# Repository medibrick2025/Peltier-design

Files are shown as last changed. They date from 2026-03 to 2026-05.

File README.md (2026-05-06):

# Peltier Brick Controller

## Description

The Peltier Brick is a modular controller designed to operate two independent Peltier heating and cooling modules. Each channel uses an IR2113 gate driver together with IRF3205 MOSFETs to form a switching stage that allows bidirectional current flow. By reversing the current through the Peltier device, the system can provide both heating and cooling.

A microcontroller generates PWM signals to regulate the power delivered to each Peltier element and control the temperature of each channel independently.

---

## PCB Layout

The images below show the front and back sides of the PCB design.

<p align="center">
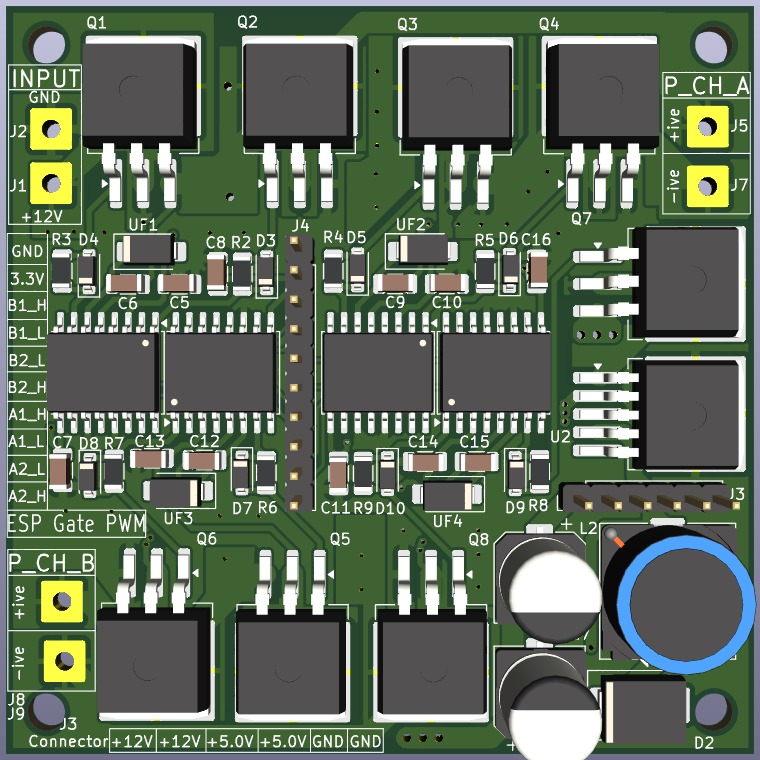
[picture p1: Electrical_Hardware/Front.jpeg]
PCB Front Side
  
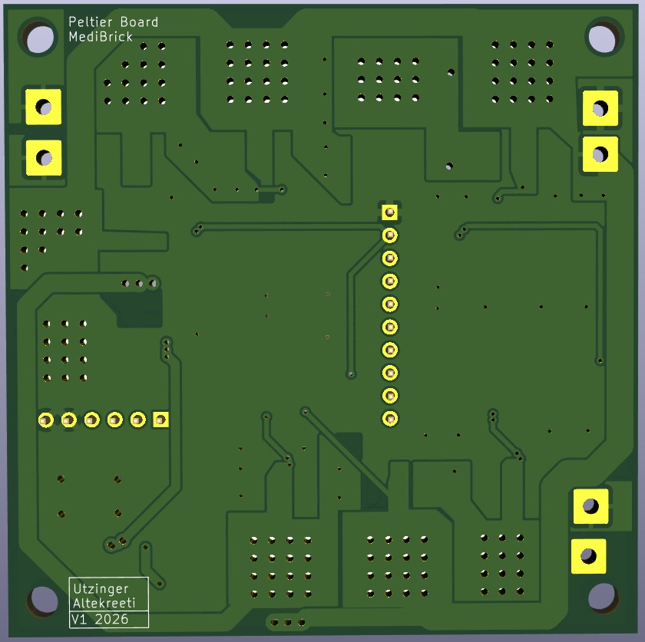
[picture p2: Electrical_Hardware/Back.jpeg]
PCB Back Side
  
</p>

## Schematics

The image below shows the circuit schematic for the PCB.

<p align="center">
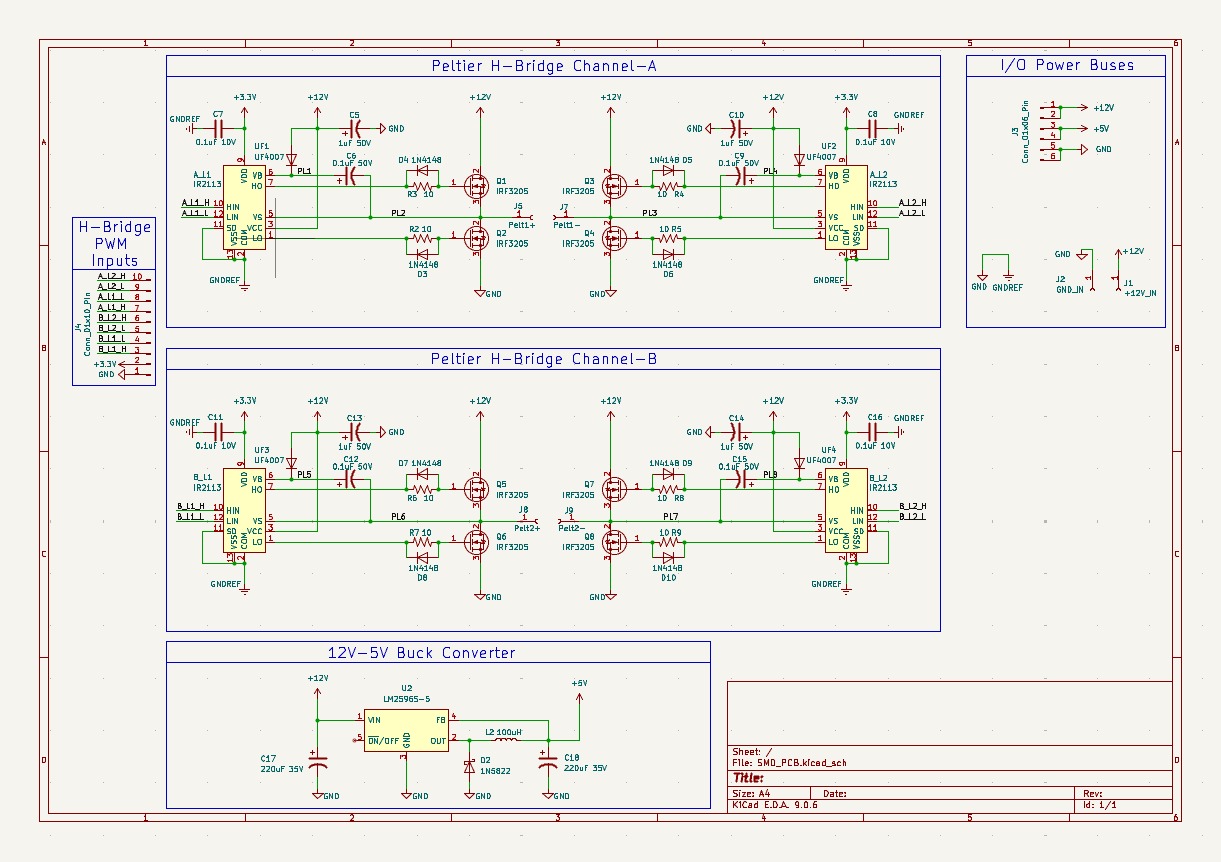
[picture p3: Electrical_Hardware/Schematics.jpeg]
PCB Schematics
  
</p>

---

## Electrical Hardware

KiCad PCB design files and manufacturing outputs:

[Electrical Hardware](Electrical_Hardware/)

---

## GUI

The project also includes a graphical user interface (GUI) for system control and monitoring.

The GUI supports basic interaction with the Peltier system, including control input and display of system status.

[GUI](GUI/)

---

## Datasheets and Design Notes

Power driver discussion and reference documentation:

[DataSheet](DataSheet/)

---

## Assembly and instructions

These are the [Assebly and Instructions](Assembly_and_instructions/)

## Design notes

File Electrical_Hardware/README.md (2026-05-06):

# PCB Ordering Guide

This folder contains the PCB manufacturing files for the Peltier hardware system.  

## PCB File Locations

```text
Electrical_Hardware/12V_PCB/SMD_PCB/
Electrical_Hardware/48V_PCB/SMD_PCB_HV/
Electrical_Hardware/Faceplate_PCB/
```

## How to Order the PCB

1. Download this repository from GitHub by clicking **Code → Download ZIP**, or clone it with Git.  

2. Open the `Electrical_Hardware` folder and choose the PCB folder you want to order.  

3. Compress the selected PCB folder into a `.zip` file.  

```text
12V_PCB/SMD_PCB/       →  SMD_PCB.zip
48V_PCB/SMD_PCB_HV/    →  SMD_PCB_HV.zip
Faceplate_PCB/         →  Faceplate_PCB.zip
```

4. Upload the `.zip` file to PCBWay as the Gerber file package.  

5. Check the PCB preview, confirm the order settings, and submit the order.  

PCBWay will review the files before manufacturing.

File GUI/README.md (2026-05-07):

## 1. Enable TTL Mode

Before using the display with the ESP32 or other microcontrollers:

Locate the TTL/232 jumper pads on the back of the display.
Enable **TTL mode** by soldering or shorting the bridge labeled:
- **ON = TTL**
- **OFF = 232**

### TTL OFF Default

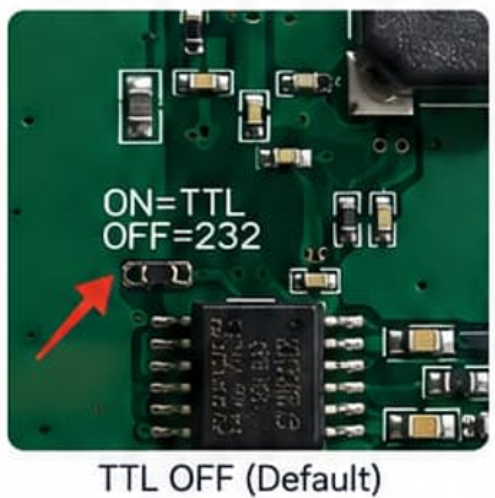
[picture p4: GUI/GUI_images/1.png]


**Figure:** TTL mode is OFF by default.

### TTL ON Shorted

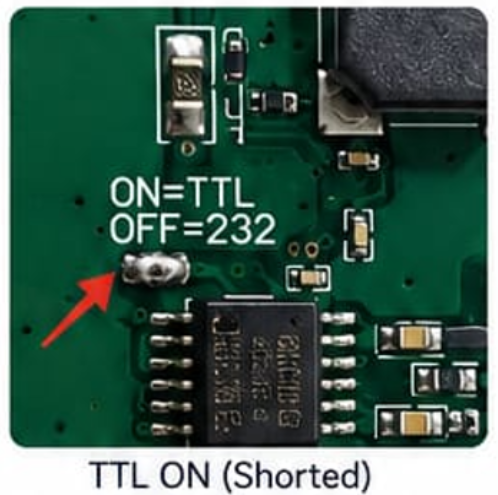
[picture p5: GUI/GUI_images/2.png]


**Figure:** Short the bridge to enable TTL mode.

> **Important:** If TTL mode is not enabled, the display may not communicate correctly with the controller.

---

## 2. Prepare the SD Card



Download the Dwin_Set folder provided with your GUI files.
Use a high-quality SD card (16GB or larger recommended).
Format the SD card to FAT32 if needed.
Copy the entire Dwin_Set folder to the root directory of the SD card.
- High-quality SD card preferred

---

## 3. Flash the GUI to the Display

### Step 1: Power the Display

Power the display using:

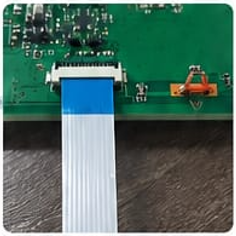
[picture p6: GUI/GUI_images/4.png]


The ribbon cable power connection, or
5V and GND wires.

### Step 2: Insert the SD Card WHILE the Display is ON

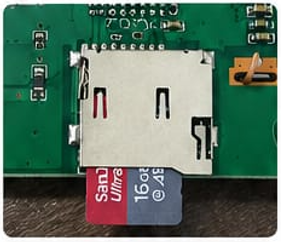
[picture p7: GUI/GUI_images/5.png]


Insert the SD card into the display while the display remains powered ON..

### Step 3: Wait for the Update Screen

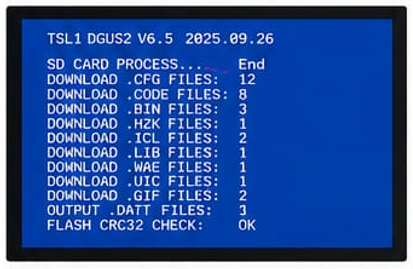
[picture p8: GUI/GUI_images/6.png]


( Keep the SD card inside and turn off the display while the Sd card in inside then turn it back on ) A blue update screen will appear. The display will begin downloading and flashing the GUI files.

Wait until the screen shows **End** on the top right.

Do not remove power or remove the SD card during this process.

---

## 4. Restart the Display and Remove the SD Card

### Step 1: Disconnect Power

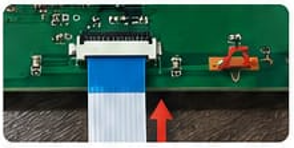
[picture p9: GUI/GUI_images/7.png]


After the update is complete, disconnect the power from the display.

### Step 2: Remove the SD Card

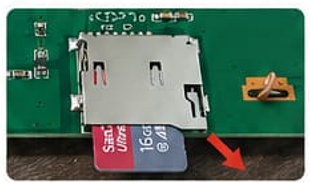
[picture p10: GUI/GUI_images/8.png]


Remove the SD card from the display.

### Step 3: Power the Display Again



Turn the power back on after removing the SD card.

---

## 5. GUI Ready

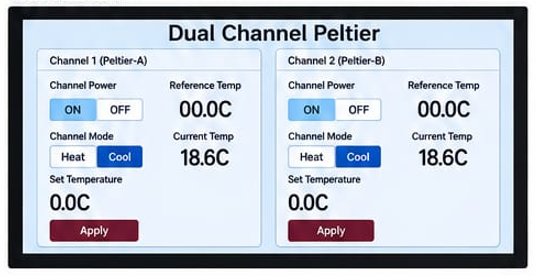
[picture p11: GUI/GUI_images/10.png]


After restarting the display, the Dual Channel Peltier GUI should appear.

The display is now ready to use with the Peltier controller.

---

## Basic Setup Summary

1. Enable TTL mode by shorting the TTL bridge.
2. Copy the complete `Dwin_Set` folder to an SD card.
3. Power the display with 5 V.
4. Insert the SD card into the display.
5. turn off the display while SD card is inside then turn it back on 
6. wait untill the blue update screen shows End 
7. disconnect from power and remove SD card 
8. turn the display on and the GUI is ready to Use.
9. Confirm that the GUI appears on the screen.

---

## Notes

- Use a high-quality SD card, preferably 16 GB or larger.
- Format the SD card as FAT32 if the update fails.
- Do not remove power while the display is updating.
- Do not remove the SD card during the update process.
- Always enable TTL mode before connecting the display to the ESP32 controller.
- If the GUI does not appear after restart, repeat the update process with a freshly formatted SD card.

---

## Important Warning

**Always enable TTL mode before flashing or using the display.**

If TTL mode is not enabled, the display may not communicate correctly with the ESP32 controller.

---
<p align="center">
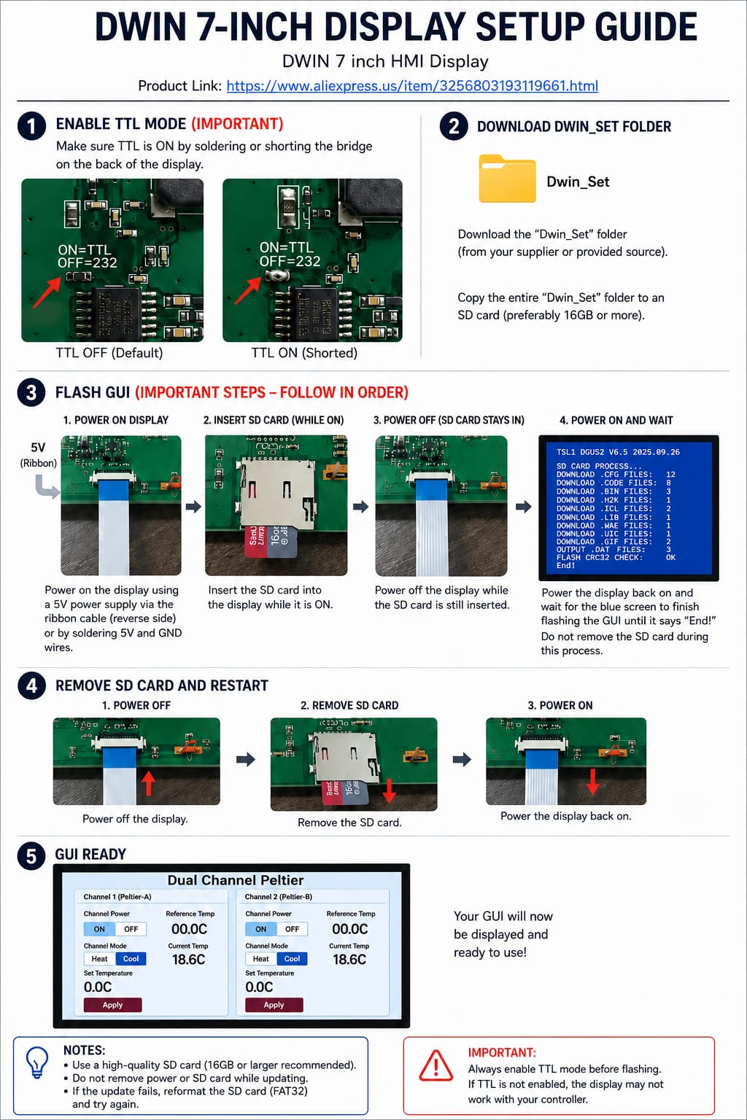
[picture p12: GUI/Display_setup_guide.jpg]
DWIN display setup guide
  
</p>

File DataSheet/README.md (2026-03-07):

## Here is the DataSheet and Power Solutions

[DataSheet](IR2113SPBF.pdf)

[Power Solutions](power_solutions.md)

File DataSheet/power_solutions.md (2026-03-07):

# Power Control Solutions

## Breakout Boards
| Source | Link | Voltage | Amperage | Logic| Cost |
| --- |--- |--- |--- |--- | --- |
| Amazon L298N |[Link](https://a.co/d/1e84QhE)|  5-35V | 2A | 5V | $3.50
| Amazon BTS7960 | [Link](https://a.co/d/3osQzfE) | 6V-27V | 43A | 3.3-5V|  $7
| Amazon DRV8871 | [Link](https://a.co/d/hwcKjuL) | 6.5-45V| 3.6A | 1.8-5V |  $4.50
| Pololu Simple Motor Driver| [Link](https://www.pololu.com/product/1365)| 6.5-50V| 12A| USB |$135
| Pololu 8874 | [Link](https://www.pololu.com/product/4035) | 37V | 2.1A | 1.8-5V | $12
| Pololu 8876 | [Link](https://www.pololu.com/product/4036) | 37V | 1.3A | 1.8-5V | $9
| Sparkfun L298| [Link](https://www.sparkfun.com/sparkfun-ardumoto-motor-driver-shield.html) | 46V | 2A |3.3-5V| $25
| Sparkfun TB6612| [Link](https://www.sparkfun.com/tb6612-1-2a-dc-stepper-motor-driver-breakout-board.html)|  15V | 1.2A | 5V | retired
| Adafruit DRV8833| [Link](https://www.adafruit.com/product/3297) | 10V | 2A | | $6
| Adafruit DRV8871| [Link](https://www.adafruit.com/product/3190)| 6.5-45V | 3.6A| 1.8-5V | $7.50

## Discrete Builds

### Gate driver IR2113 and FET IRF3205
IRF3205 is *outdate design*

- requires 12V gate driver
- IRF3205 55V, 110A, 8mOhm, $1.45
- requires careful timing
- external current Senses
- allows for high switching rates

Optimizations with replacement parts

Replace FET with:

| Device | Voltage | Current | RDS ON | Price
| --- | --- | --- | --- | --- |
| IRLB3034 | 40V | 195-300A | 1.7mOhm | $2-4, end of life
| IRLB8743 | 30V | 150A | 3.2mOhm | $ 0.7-1.5 
| BSC010NE2LS | 25V |  100A | 1.1mOhm | $3-5
| AOI4184 | 40V | 40-50A| 7-8 mOhm | $0.7
| AOI518 | 30V | 54A | 8mOhm | obsolete
| BSC340N08 | 80V | 23A | 34mOhm | $1.30
| IPB017N10N5 | 100V |  120-180A| 1.5mOhm | $5-7
| IPB017N06N5 | 60V |  100-180A|  1.7mOhm | $6.25
| IPP034N06L3 | 30V | 80A | 3.4mOhm | $1-2 restricted availability
| STN3NF06L | 60V | 4A | 100mOhm | $1.59
| FQP30N06L | 60V | 32A | 35mOhm | $1.8
| onsemi RFP50N06| 60V | 50A | 22mOhm | $0.83
| NTE2996 | 60V | 84A  | 12mOhm | $2.85
| **TI CSD18532Q5B**| 60V | 100A | 3.2mOhm | $2.99 US $1.58 CHN
| **TI CSD18540Q5B**| 60V | 100A | 2.2mOhm | $3.05 US $1.51 CHN

Gate Drivers:

- UCC27211A 12V gate, simple no current sense, half bridge, $2.60
- IRS2186 10-20V gate, simple not current sense, half bridge $1.95
- MP6528 12V gate, full bridge, protection circuits, for 5-60V FET $2.51 (no stock JLPCP, in stock US)

- **Smart Gate Driver**, full bridge [DRV8701](https://www.ti.com/product/DRV8701) for 47V FET. $2.85 US, $0.59 CHN

- **Smart Gate Driver**, 2 x full bridge [DRV8704](https://www.ti.com/product/DRV8704) for 47 FET.  $4.87 US, $5.54 CHN

Also check out example design from Texas Instruments for [single H bridge](https://www.ti.com/tool/DRV8701EVM) and for [Dual H bridge](https://www.ti.com/tool/DRV8704EVM) with eval kit for $60.

### "Smart" H Bridge: Infinion BTS7960 / BTN7970 / BTN8982
*breakout board available*

builtin protection, simpler

half bridge:
- BTS7960 45V, 43A, 25kHz, 16mOhm, 5V logic, current sense, no stock china, USA
- BTN7960 45V, 44A, 25kHz, 30mOhm, 5V logic, current sense, no stock
- BTN7970 45V, 44A, 25kHz, 30mOhm, 5V logic, current sense, $5 obsolete
- **BTN8982** 40V, 44A, 25kHz, 20mOhm, 5V logic, current sense (newer) $3.82 CHN $5.6 US

Requires 3V to 5V logic buffer with TI SN74HCS244 to operate with 3.3V micro controllers

Also check out example design from infinion on [hackster](https://www.hackster.io/infineon/products/dc-motor-control-shield-with-btn8982ta?ref=project-0f6579)

P = I x R x I = 160*0.02 = 3.2 W heat @ 40A

### Integrated H Bridge DRV8874 / DRV8876 / DRV887x
*breakout board available*

Easy to use
builtin current limit or current sense
simple interface

- DRV8871 6.5 - 45V, 3.6A, protection, current limiter
- DRV8876 4.5 - 37V, 3.5A, 700mOhm, 1.8-5V logic, current sense output
- DRV8874 4.5 - 37V, 6A, 200mOhm, 1.8-5V logic, current sense output, $3 

P = I x R x I 36*0.2 = 7.2 W heat @ 6A

This is lower cost and fully integrated solution but thermal management at 6A will require careful design as it has high RDSON

### Half H Bridge DRV81XX
- DRV8145 4.5 - 35V, 46A, 16mOhm, 125kHz, $6.87, half bridge only
- DRV8144 4.5 - 35V, 30A, 24mOhm $5.50, half bridge only

## Temperature
ADS1220
 
> Adapted from the MediBrick project:  
> https://github.com/MediBrick/MediBrick/blob/main/power_solutions.md

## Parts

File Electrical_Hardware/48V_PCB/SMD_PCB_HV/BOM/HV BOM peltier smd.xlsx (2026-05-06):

Item # | Designator | Qty | Manufacturer | Mfg Part # | LCSC Part# | Description / Value | Packaging | Type | Cost | Footprint | Remark
1 | Q1,Q2,Q3,Q4,Q5,Q6,Q7,Q8 | 8 | HXY MOSFET (https://www.lcsc.com/brand-detail/13437.html) | IRFS4310ZTRLPBF-HXY | C20606279 (https://www.lcsc.com/product-detail/C20606279.html?s_z=n_IRFS4310Z) | N-Channel 100V 260A 379W Surface Mount TO-263 | TO-263 | SMD |  | TO-263-3_TabPin2
2 | R9,R6,R4,R2,R5,R3,R8,R7 | 8 | YAGEO (https://www.lcsc.com/brand-detail/396.html) | RC1206FR-0710RL | C108080 (https://www.lcsc.com/product-detail/C108080.html?s_z=n_RC1206FR-0710) | RES 10Ω ±1% 250mW 1206 | 1206 | SMD |  | R_1206_3216Metric
3 | B_L2,A_L2,A_L1,B_L1 | 4 | Minos (https://www.lcsc.com/brand-detail/13052.html) | IR2113S-MNS | C47967297 (https://www.lcsc.com/product-detail/C47967297.html?s_z=n_%2509%2520IR2113) | IR2113 | SOIC-16 | SMD |  | SOIC-16W_7.5x10.3mm_P1.27mm
4 | C16,C8,C11,C7 | 4 | Samsung Electro-Mechanics (https://www.lcsc.com/brand-detail/254.html) | CL31B104KBCNNNC | C24497 (https://www.lcsc.com/product-detail/C24497.html?s_z=n_0.1uF%252010V%25201206) | 0.1uF 50V | 1206 | SMD |  | C_1206_3216Metric
5 | D5,D6,D10,D4,D8,D9,D3,D7 | 8 | JSMSEMI (https://www.lcsc.com/brand-detail/12313.html) | 1N4148W | C917030 (https://www.lcsc.com/product-detail/C917030.html?s_z=n_1N4148%2520sod-123) | 1N4148 | D_SOD-123 | SMD |  | D_SOD-123
6 | C14,C13,C10,C9,C12,C5,C6,C15 | 8 | YAGEO (https://www.lcsc.com/brand-detail/396.html) | AC1206KKX7R0BB105 | C2936627 (https://www.lcsc.com/product-detail/C2936627.html) | 1uF ±10% 100V Ceramic Capacitor X7R 1206 | 1206 | SMD |  | C_1206_3216Metric
7 | R1 | 1 | YAGEO (https://www.lcsc.com/brand-detail/396.html) | RT0805FRE07215KL | C706379 (https://www.lcsc.com/product-detail/C706379.html?s_z=n_RES%2520215k%25CE%25A9_0805) | RES 215kΩ ±1% 125mW 0805 | R_0805_2012Metric | SMD |  | R_0805_2012Metric
8 | R10 | 1 | YAGEO (https://www.lcsc.com/brand-detail/396.html) | RT0805BRD0744K2L | C865498 (https://www.lcsc.com/product-detail/C865498.html) | RES 44.2kΩ ±0.1% 125mW 0805 | 805 | SMD |  | R_0805_2012Metric
9 | R14,R15 | 2 | YAGEO (https://www.lcsc.com/brand-detail/396.html) | RC0805FR-07100KL | C96346 (https://www.lcsc.com/product-detail/C96346.html) | RES 100kΩ ±1% 125mW 0805 | 805 | SMD |  | R_0805_2012Metric
10 | R11 | 1 | YAGEO | RC0805FR-07147KL | C483012 (https://www.lcsc.com/product-detail/C483012.html?s_z=n_RC0805FR-07147KL) | RES 147kΩ ±1% 125mW 0805 | 805 | SMD |  | R_0805_2012Metric
11 | R16 | 1 | FOJAN | FRC0805F2323TS | C2974036 (https://www.lcsc.com/product-detail/C2974036.html) | RES 232kΩ ±1% 125mW 0805 | 805 | SMD |  | R_0805_2012Metric
12 | R17 | 1 | YAGEO | RC0805FR-0730KL | C126352 (https://www.lcsc.com/product-detail/C126352.html?s_z=n_RC0805FR-0730KL) | RES 30kΩ ±1% 125mW 0805 | 805 | SMD |  | R_0805_2012Metric
13 | R12 | 1 | UNI-ROYAL (https://www.lcsc.com/brand-detail/99.html) | 0805W8F1052T5E | C40086 (https://www.lcsc.com/product-detail/C40086.html) | RES 10.5kΩ ±1% 125mW 0805 | 805 | SMD |  | R_0805_2012Metric
14 | R13 | 1 | YAGEO (https://www.lcsc.com/brand-detail/396.html) | RC0805FR-071ML | C107700 (https://www.lcsc.com/product-detail/C107700.html?s_z=n_RC0805FR-010R5KL) | RES 1MΩ ±1% 125mW 0805 | 805 | SMD |  | R_0805_2012Metric
15 | U1 | 1 | TI (https://www.lcsc.com/brand-detail/100.html) | TPS54360DDAR | C44377 (https://www.lcsc.com/product-detail/C44377.html?s_z=n_TPS54360DDA) | 60V Input, 3.5A Output Step-Down DC-DC Converter | SOIC-8-EP | SMD |  | TI_SO-PowerPAD-8_ThermalVias
16 | U4 | 1 | TI (https://www.lcsc.com/brand-detail/100.html) | TPS562203DRLR | C22445511 (https://www.lcsc.com/product-detail/C22445511.html?s_z=n_TPS562203) | 4.2V to 17V Input, 2A Output, Synchronous Buck Converter | SOT-563 | SMD |  | SOT-563
17 | C1 | 1 | Samsung Electro-Mechanics (https://www.lcsc.com/brand-detail/254.html) | CL32B225KCJSNNE | C55151 (https://www.lcsc.com/product-detail/C55151.html?s_z=n_2.2uF%2520100V%25201210) | 2.2uF ±10% 100V Ceramic Capacitor X7R 1210 | 1210 | SMD |  | C_1210_3225Metric
18 | C2 | 1 | YAGEO (https://www.lcsc.com/brand-detail/396.html) | AS0805KRX7R0BB472 | C1853298 (https://www.lcsc.com/product-detail/C1853298.html?s_z=n_4.7nF%2520100V%25200805) | 4.7nF X7R ±10% 100V 0805 Ceramic Capacitors RoHS | 805 | SMD |  | C_0805_2012Metric
19 | C3 | 1 | MEGSINE | MCA08HQ8R2C251T7 | C42432098 (https://www.lcsc.com/product-detail/C42432098.html?s_z=n_CAP%2520CER%25208.2pF%2520100V%25200805) | CAP CER 8.2pF 250V 0805 | 805 | SMD |  | C_0805_2012Metric
20 | C24 | 1 | YAGEO (https://www.lcsc.com/brand-detail/396.html) | CC0805MKX5R6BB226 | C109314 (https://www.lcsc.com/product-detail/C109314.html) | CAP CER 22uF 10V X5R 0805 | 805 | SMD |  | C_0805_2012Metric
21 | C23 | 1 | muRata (https://www.lcsc.com/brand-detail/79.html) | GRM0335C1E180FA01D | C488333 (https://www.lcsc.com/product-detail/C488333.html?s_z=n_%2509%2520C488333) | CAP CER 18pF 25V C0G 0201 | 201 | SMD |  | C_0201_0603Metric
22 | C4,C21,C22,C25 | 1 | YAGEO (https://www.lcsc.com/brand-detail/396.html) | CC0603KRX7R9BB104 | C14663 (https://www.lcsc.com/product-detail/C14663.html?s_z=n_100nF%252050V%25200603) | CAP CER 100nF 50V X7R 0603 | 603 | SMD |  | C_0603_1608Metric
24 | C20 | 1 | CCTC (https://www.lcsc.com/brand-detail/11714.html) | TCC0805X5R106K250FT | C5448891 (https://www.lcsc.com/product-detail/C5448891.html?s_z=n_10uF%252025V%25200805) | CAP CER 10uF 25V X5R 0805 | 805 | SMD |  | C_0805_2012Metric
25 | C19 | 1 | Chinocera (https://www.lcsc.com/brand-detail/12099.html) | HGC1206R5476M250NSPJ | C22367835 (https://www.lcsc.com/product-detail/C22367835.html?s_z=n_47uF%252025V%25201206) | CAP CER 47uF 25V X5R 1206 | 1206 | SMD |  | C_1206_3216Metric
26 | D13,D12,D2,D11 | 4 | VISHAY (https://www.lcsc.com/brand-detail/91.html) | US1M-E3/61T | C81191 (https://www.lcsc.com/product-detail/C81191.html?s_z=n_US1M) | Diode 1kV 1A SMA(DO-214AC) | SMA(DO-214AC) | SMD |  | D_SMA
27 | D15 | 1 | MDD(Microdiode Semiconductor) (https://www.lcsc.com/brand-detail/164.html) | SS510B | C65011 (https://www.lcsc.com/product-detail/C65011.html?s_z=n_SS510B) | DIODE SCHOTTKY 100V SMB(DO-214AA) | SMB(DO-214AA) | SMD |  | D_SMB
28 | L3 | 1 | cjiang (https://www.lcsc.com/brand-detail/11425.html) | FTC404030S6R8MBCA | C39676084 (https://www.lcsc.com/product-detail/C39676084.html) | FIXED IND 6.8uH 4.2A 62mΩ SMD,4.1x4.1mm | SMD,4.1x4.1mm | SMD |  | L_Changjiang_FTC404030S
29 | L1 | 1 | BOURNS (https://www.lcsc.com/brand-detail/377.html) | SRR1260-220M | C3224283 (https://www.lcsc.com/product-detail/C3224283.html?s_z=n_L_Bourns_SRR1260) | 4A 22uH 43mΩ 3.7A ±20% SMD,12.5x12.5mm Fixed Inductors RoHS | SMD,12.5x12.5mm | SMD |  | L_Bourns_SRR1260
30 | J4 | 1 | JST (https://www.lcsc.com/brand-detail/853.html) | B10B-PHDSS-B(LF)(SN) | C158039 (https://www.lcsc.com/product-detail/C158039.html) |  |  |  |  | JST_PHD_B10B-PHDSS_2x05_P2.00mm_Vertical
31 | J1,J2,J6 | 3 | Changzhou Amass Elec (https://www.lcsc.com/brand-detail/1029.html) | XT30PW-M30.G.Y | C431092 (https://www.lcsc.com/product-detail/C431092.html?s_z=n_AMASS_XT30PW-F_1x02_P2.50mm_Horizontal) | Banana and Tip Connector Adapters RoHS | - |  |  | AMASS_XT30PW-F_1x02_P2.50mm_Horizontal
32 | J5 | 1 |  |  |  |  |  |  |  | PinHeader_1x11_P2.54mm_Vertical | DNP

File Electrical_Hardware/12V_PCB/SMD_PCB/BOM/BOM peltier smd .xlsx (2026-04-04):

Item # | Designator | Qty | Manufacturer | Mfg Part # | LCSC Part# | U.S. Distributor | Description / Value | Packaging | Type | Cost | Footprint | Remark
1 | Q4,Q1,Q8,Q7,Q2,Q5,Q6,Q3 | 8 | JSMSEMI (https://www.lcsc.com/brand-detail/12313.html) | IRF3205S-JSM | C2874633 (https://www.lcsc.com/product-detail/C2874633.html?s_z=n_IRF3205) |  | IRF3205 55V 110A 200W Surface Mount TO-263 | TO-263 | SMD |  | TO-263-3_TabPin2
2 | R9,R6,R4,R2,R5,R3,R8,R7 | 8 | YAGEO (https://www.lcsc.com/brand-detail/396.html) | RC1206FR-0710RL | C108080 (https://www.lcsc.com/product-detail/C108080.html?s_z=n_RC1206FR-0710) |  | RES 10Ω ±1% 250mW 1206 | 1206 | SMD |  | R_1206_3216Metric
3 | D2 | 1 | onsemi (https://www.lcsc.com/brand-detail/94.html) | SS34 | C154551 (https://www.lcsc.com/product-detail/C154551.html?s_z=n_SS34) |  | Diode 40V 3A SMC(DO-214AB) | SMC(DO-214AB) | SMD |  | D_SMC
4 | UF3,UF4,UF1,UF2 | 4 | VISHAY (https://www.lcsc.com/brand-detail/91.html) | US1M-E3/61T | C81191 (https://www.lcsc.com/product-detail/C81191.html?s_z=n_US1M) |  | Diode 1kV 1A SMA(DO-214AC) | SMA(DO-214AC) | SMD |  | D_SMA
5 | C14,C13,C10,C5 | 4 | Samsung Electro-Mechanics (https://www.lcsc.com/brand-detail/254.html) | CL31B105KBHNNNE | C1848 (https://www.lcsc.com/product-detail/C1848.html?s_z=n_1uF%252050V%25201206) |  | CAP CER 1uF 50V X7R 1206 | 1206 | SMD |  | C_1206_3216Metric
6 | B_L1,B_L2,A_L2,A_L1 | 4 | Minos (https://www.lcsc.com/brand-detail/13052.html) | IR2113S-MNS | C47967297 (https://www.lcsc.com/product-detail/C47967297.html?s_z=n_%2509%2520IR2113) |  | IR2113 | SOIC-16 | SMD |  | SOIC-16W_7.5x10.3mm_P1.27mm
7 | C18,C17 | 2 | JIERR (https://www.lcsc.com/brand-detail/18279.html) | CS35V220M8X10 | C48935393 (https://www.lcsc.com/product-detail/C48935393.html?s_z=n_220uF%252035V%2520CP_Elec_8x10) |  | CAP ALUM 220uF ±20% 35V SMD | 8x10 | SMD |  | CP_Elec_8x10
8 | C16,C8,C11,C7 | 4 | Samsung Electro-Mechanics (https://www.lcsc.com/brand-detail/254.html) | CL31B104KBCNNNC | C24497 (https://www.lcsc.com/product-detail/C24497.html?s_z=n_0.1uF%252010V%25201206) |  | 0.1uF 50V | 1206 | SMD |  | C_1206_3216Metric
9 | D5,D6,D10,D4,D8,D9,D3,D7 | 8 | JSMSEMI (https://www.lcsc.com/brand-detail/12313.html) | 1N4148W | C917030 (https://www.lcsc.com/product-detail/C917030.html?s_z=n_1N4148%2520sod-123) |  | 1N4148 | D_SOD-123 | SMD |  | D_SOD-123
10 | C9,C12,C6,C15 | 4 | Samsung Electro-Mechanics (https://www.lcsc.com/brand-detail/254.html) | CL31B104KBCNNNC | C24497 (https://www.lcsc.com/product-detail/C24497.html?s_z=n_0.1uF%252010V%25201206) |  | 0.1uF 50V | 1206 | SMD |  | C_1206_3216Metric
11 | L2 | 1 | COILMX (https://www.lcsc.com/brand-detail/11934.html) | MBH125-101M | C2981396 (https://www.lcsc.com/product-detail/C2981396.html?s_z=n_C2981396) |  | 100uH 2A 178mΩ Unshielded Inductor ±20% SMD,12.5x12.5mm Fixed Inductors RoHS | SMD,12.5x12.5mm | SMD |  | SMD,12.5x12.5mm
12 | U2 | 1 | TI | LM2596S-5.0/NOPB | C116713 (https://www.lcsc.com/product-detail/C116713.html?s_z=n_LM2596S-5.0) |  | LM2596 150-kHz 3-A Step-Down Voltage Regulator | TO-263-5 | SMD |  | TO-263-5_TabPin3
13 | J1 | 1 |  |  |  |  | +12V_IN |  | SMD |  | SolderWire-1sqmm_1x01_D1.4mm_OD3.9mm | DNP
14 | J2 | 1 |  |  |  |  | GND_IN |  | SMD |  | SolderWire-1sqmm_1x01_D1.4mm_OD3.9mm | DNP
15 | J3 | 1 |  |  |  |  | Conn_01x06_Pin |  | SMD |  | PinHeader_1x06_P2.54mm_Vertical | DNP
16 | J4 | 1 |  |  |  |  | Conn_01x10_Pin |  | SMD |  | PinHeader_1x10_P2.54mm_Vertical | DNP
17 | J5 | 1 |  |  |  |  | Pelt1+ |  | SMD |  | SolderWire-1sqmm_1x01_D1.4mm_OD3.9mm | DNP
18 | J7 | 1 |  |  |  |  | Pelt1- |  | SMD |  | SolderWire-1sqmm_1x01_D1.4mm_OD3.9mm | DNP
19 | J8 | 1 |  |  |  |  | Pelt2+ |  | SMD |  | SolderWire-1sqmm_1x01_D1.4mm_OD3.9mm | DNP
20 | J9 | 1 |  |  |  |  | Pelt2- |  | SMD |  | SolderWire-1sqmm_1x01_D1.4mm_OD3.9mm | DNP

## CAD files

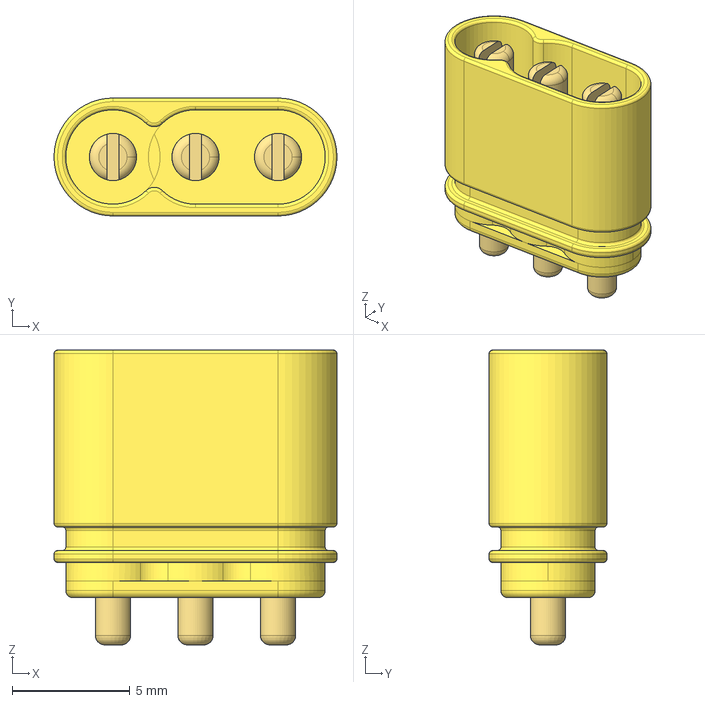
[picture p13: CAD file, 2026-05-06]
Electrical_Hardware/Faceplate_PCB/Side_Plate_PeltierBrick/Side_Plate_PeltierBrick/3dshapes/Amass_MR30PB-M.step
12.0 x 5.00 x 12.5 mm

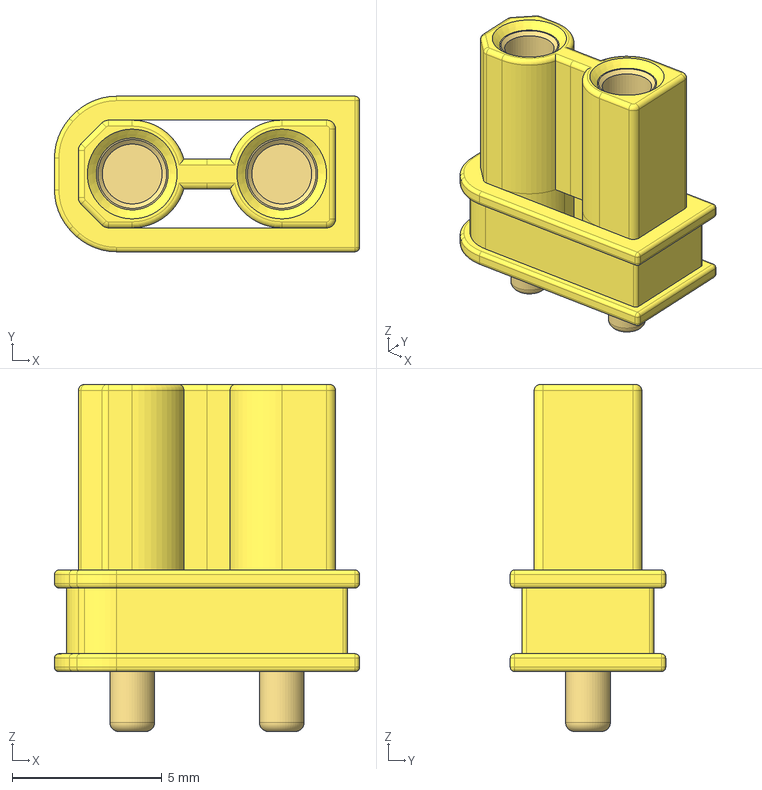
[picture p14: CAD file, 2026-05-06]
Electrical_Hardware/Faceplate_PCB/Side_Plate_PeltierBrick/Side_Plate_PeltierBrick/3dshapes/Amass_XT30UPB-F.step
10.2 x 5.20 x 11.6 mm

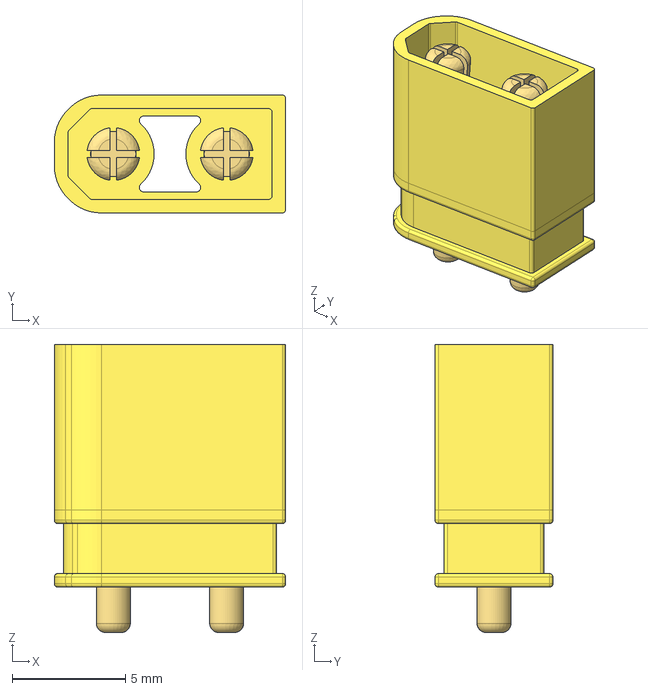
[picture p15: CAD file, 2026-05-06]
Electrical_Hardware/Faceplate_PCB/Side_Plate_PeltierBrick/Side_Plate_PeltierBrick/3dshapes/Amass_XT30UPB-M.step
10.2 x 5.20 x 12.7 mm

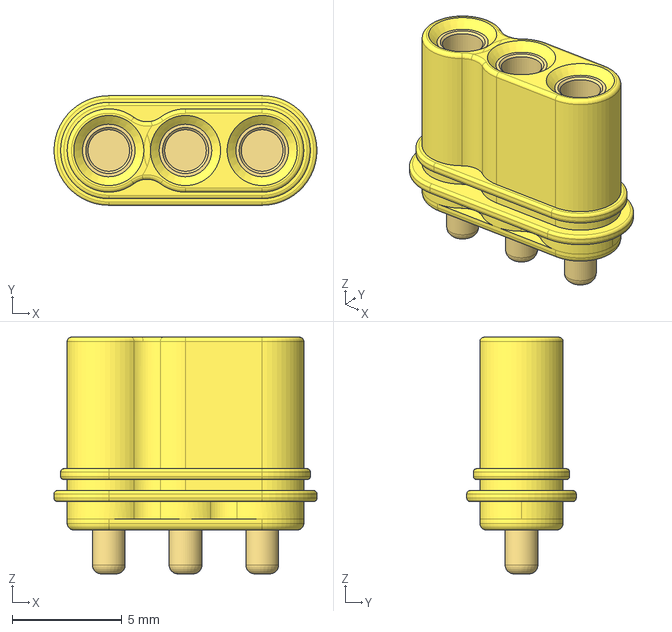
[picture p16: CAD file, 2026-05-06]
Electrical_Hardware/Faceplate_PCB/Side_Plate_PeltierBrick/Side_Plate_PeltierBrick/3dshapes/Amass_MR30PB-FB.step
12.0 x 5.00 x 10.8 mm

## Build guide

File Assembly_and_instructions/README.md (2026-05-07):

## 1. Components

| Component | Image | Description |
|---|---|---|
| TMP36GZ Temperature Sensor |  | Analog temperature sensor |
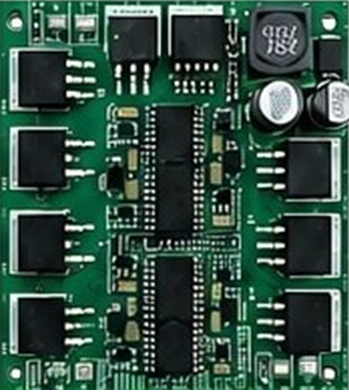
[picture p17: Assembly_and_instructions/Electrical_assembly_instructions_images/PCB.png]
| Motor Driver PCB |  | Main motor driver and power board |
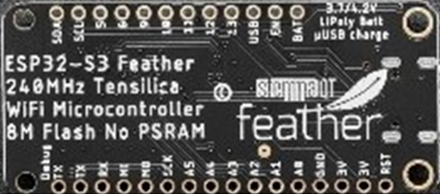
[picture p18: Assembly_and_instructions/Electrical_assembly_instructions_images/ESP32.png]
| ESP32-S3 Feather |  | Microcontroller board |
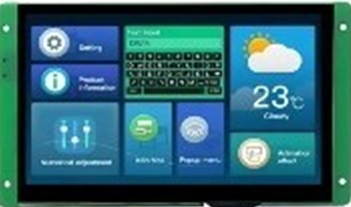
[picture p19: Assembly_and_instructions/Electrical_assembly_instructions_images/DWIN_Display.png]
| DWIN Display 7 inch |  | 7 inch DWIN HMI Display |
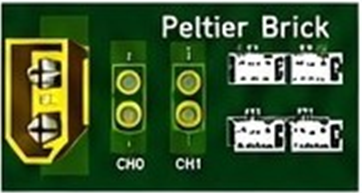
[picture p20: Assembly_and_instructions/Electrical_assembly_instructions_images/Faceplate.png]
| Face Plate |  | Panel with connectors and labels |

---

## 2. PCB to ESP32-S3 Connections

| PCB Signal | ESP32-S3 Pin | Description |
|---|---|---|
| 3.3V | 3V3 | ESP 3.3V power |
| GND | GND | Ground |
| B1-H | 5 | High Side B1 |
| B1-L | 6 | Low Side B1 |
| B2-L | 9 | Low Side B2 |
| B2-H | 10 | High Side B2 |
| A1-H | 11 | High Side A1 |
| A1-L | 12 | Low Side A1 |
| A2-L | 13 | Low Side A2 |
| A2-H | 8 / A5 | High Side A2 / Analog |
| 5V | USB | 5V power from USB |

**Tip:** Use short, twisted wires for motor outputs to reduce EMI.

---

## 3. TMP36 Temperature Sensor to ESP32-S3 Connections

| TMP36 Pin | ESP32-S3 Pin | Description |
|---|---|---|
| Pin 1 | VCC / 3V3 | DC voltage input, +2.7 V to 5.5 V |
| Pin 2 | A0 / Analog | Analog voltage output |
| Pin 3 | GND | Ground |

### Important TMP36 Wiring Note

Before connecting the TMP36 sensor to the ESP32:

1. Use a laboratory power supply set between 3 V and 5 V.
2. Set the current limit as low as possible.
3. Temporarily connect the TMP36 to the power supply.
4. Use a multimeter to verify the VCC and GND legs.
5. Confirm correct polarity before connecting the sensor to the ESP32.

**Warning:** Incorrect VCC/GND wiring may damage the sensor or microcontroller.



**Figure:** TMP36GZ temperature sensor reference.

---

## 4. DWIN Display to ESP32 and PCB Connections

| DWIN 7 inch | PCB Signal | ESP32-S3 Pin | Description |
|---|---|---|---|
| 5V | 5V | N.C. | Display power 5V |
| GND | GND | GND | Ground |
| RX2 | N.C. | TX2 | DWIN RX connects to ESP TX2 |
| TX2 | N.C. | RX2 | DWIN TX connects to ESP RX2 |

**Note:** `N.C.` means Not Connected.

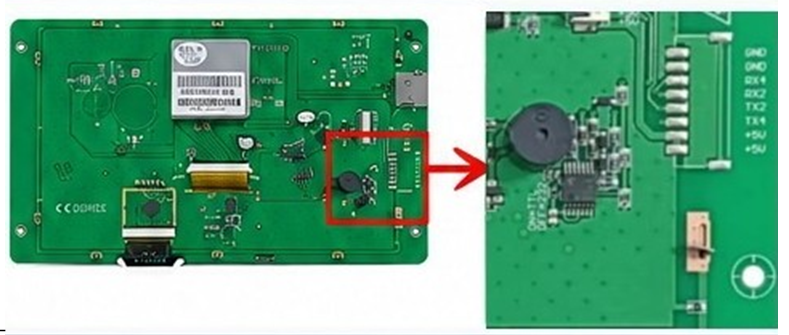
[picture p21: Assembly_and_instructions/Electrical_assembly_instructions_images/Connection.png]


**Figure:** DWIN display connection area and connector pin reference.

---

## 5. PCB to Face Plate Connections

| Face Plate Connection | PCB Connection | Description |
|---|---|---|
| XT60 Input | Power Supply Input | +12 V power input |
| CH0 XT30 | P_CH_A | Peltier Channel 0 |
| CH1 XT30 | P_CH_B | Peltier Channel 1 |

### Connector Notes

- XT60 provides the power supply input, **+12 V**.
- CH0 and CH1 use XT30 connectors for the Peltier brick channels.
- Ensure correct polarity before connecting the Peltier brick.
- RT1, RT2, RT3, and RT4 are for temperature sensor connections.

| Connector | Image | Description |
|---|---|---|
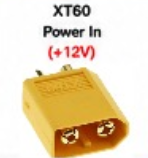
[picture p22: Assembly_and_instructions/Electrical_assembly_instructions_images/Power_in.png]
| XT60 Power Input |  | +12 V power input |
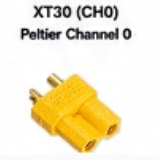
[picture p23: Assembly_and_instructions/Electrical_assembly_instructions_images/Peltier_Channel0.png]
| XT30 Channel 0 |  | Peltier Channel 0 |
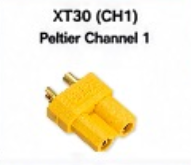
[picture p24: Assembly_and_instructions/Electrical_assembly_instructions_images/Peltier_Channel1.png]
| XT30 Channel 1 |  | Peltier Channel 1 |

---

## 6. Additional Recommendations

- Add a main inline fuse, 10–15 A, on the +12 V input.
- Add TVS diode protection on the +12 V input for surge protection.
- Add a bulk capacitor, 470–1000 µF, near the power input.
- Keep high-current motor and Peltier wiring away from signal wires.
- Use cable ties and strain relief to secure all wiring.
- Ensure proper ventilation for heat dissipation.

---

## 7. Final Assembly Notes

Before powering the system:

- Verify all wiring before powering the system.
- Ensure all grounds are shared properly.
- Double-check XT30 and XT60 polarity before applying power.
- Verify TMP36 orientation before connecting power.
- Use insulated wiring and avoid short circuits during assembly.
- Refer to the wiring AWG and ampacity guide to select wires for input power.
- A minimum of 16 AWG wire is recommended for the main power input.

### AWG Current Capacity Guide

| AWG | Maximum Current |
|---|---|
| 14 AWG | 30 A |
| 16 AWG | 20 A |
| 18 AWG | 15 A |
| 20 AWG | 10 A |

---

## 8. Important Warning

**Do not power the Peltier device from a power supply while the ESP32 is connected to a laptop USB port.**

This may damage the laptop USB port.

---

## 9. Wiring Color Guide Recommended

| Color | Signal |
|---|---|
| Red | +12 V input |
| Red | +5 V / +3.3 V |
| Black | GND |
| Blue | Motor outputs A1, A2, B1, B2 |
| Yellow | Peltier outputs CH0, CH1 |
| Green | Signal / UART / I/O |
| Purple | Analog TMP36 |

---

## 10. Tools Required

- Soldering iron
- Multimeter
- Wire stripper / cutter
- Crimping tool
- Heat shrink tubing
- Screwdriver set

---

## 11. Checklist Before Power On

- [ ] All connections are secure and polarity is correct.
- [ ] No loose strands or shorts are on the PCB.
- [ ] TMP36 is wired correctly: Pin 1 to 3V3, Pin 2 to A0, Pin 3 to GND.
- [ ] All grounds are common.
- [ ] Power supply current limit is set.

---

# Part 2: User Manual

## 1. Overview

The Dual Channel Peltier Device allows independent temperature control for two channels using Peltier thermoelectric technology.

Each channel can be set to **Heat** or **Cool** mode with a desired target temperature.

---

## 2. Main Screen Overview

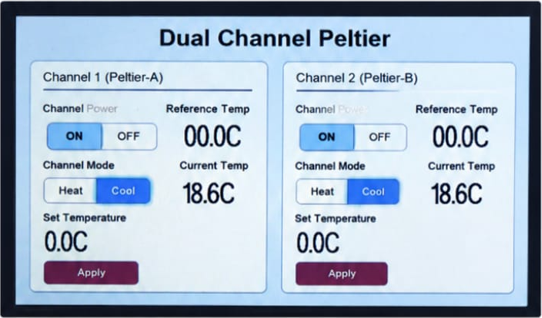
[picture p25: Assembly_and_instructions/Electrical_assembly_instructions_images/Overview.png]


**Figure:** Main screen overview of the Dual Channel Peltier interface.

The main screen contains two independent control panels:

- **Channel 1 (Peltier-A)**
- **Channel 2 (Peltier-B)**

Each channel includes:

- Channel Power control
- Heat / Cool mode selection
- Set Temperature input
- Reference Temperature display
- Current Temperature display
- Apply button

---

## 3. How to Set the Temperature

### Step 1: Tap the Set Temperature Value

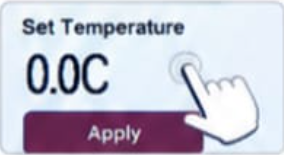
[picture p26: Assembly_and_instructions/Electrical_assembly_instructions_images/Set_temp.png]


On the main screen, tap the **Set Temperature** value in the channel panel.

This value is located near the bottom-left area of each channel panel.

---

### Step 2: Numeric Keypad Appears

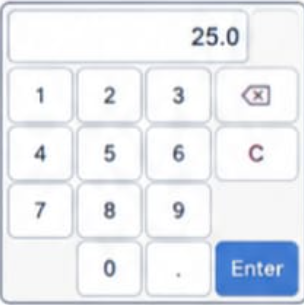
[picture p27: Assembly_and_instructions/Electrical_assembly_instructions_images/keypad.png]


A numeric keypad will appear after tapping the temperature value.

---

### Step 3: Enter the Desired Temperature

Use the keypad to enter the target temperature.

Example:

```txt
25.0
```

---

### Step 4: Tap Enter to Confirm

After entering the desired temperature, tap **Enter** to confirm.

The system will return to the main screen after confirmation.

---

### Step 5: Check the Updated Temperature

The new set temperature will now be displayed on the main screen.

---

## 4. How to Start Heating or Cooling

### Step 1: Choose Heat or Cool Mode



After setting the target temperature, choose the desired channel mode:

- **Heat** — increases the temperature.
- **Cool** — decreases the temperature.

---

### Step 2: Turn On the Channel Power



Turn on the channel by selecting **ON** under **Channel Power**.

Each channel can be controlled independently.

---

### Step 3: Monitor the Current Temperature



The system will start moving toward the set temperature.

The **Current Temp** value will update in real time.

---

## 5. Basic Operation Summary

1. Select the desired channel.
2. Tap the **Set Temperature** value.
3. Enter the desired temperature using the keypad.
4. Tap **Enter** to confirm.
5. Select **Heat** or **Cool** mode.
6. Turn the channel power **ON**.
7. Monitor the **Current Temp** value.

---

## 6. Operation Notes

- Channel 1 and Channel 2 can operate independently.
- Make sure the Peltier module is connected before starting heating or cooling.
- Do not touch the Peltier surface during operation because it may become hot or cold.
- Verify the temperature sensor connection before powering the system.
- If the displayed temperature does not change, turn off the channel and check the wiring.
- If the system behaves abnormally, turn off the power immediately and inspect all connections.

---

## 7. Quick Troubleshooting

| Problem | Possible Cause | Suggested Check |
|---|---|---|
| Display does not turn on | No 5V power or loose wiring | Check DWIN 5V and GND connections |
| Temperature does not update | TMP36 wiring issue | Check TMP36 Pin 1, Pin 2, and Pin 3 |
| Peltier does not heat or cool | Channel power is OFF or connector is loose | Check ON/OFF switch and XT30 connection |
| Wrong heating/cooling direction | Mode selection or Peltier polarity issue | Check Heat/Cool mode and connector polarity |
| System resets or behaves abnormally | Power supply issue or short circuit | Turn off power and inspect wiring |

---

## Purchase

Order the display from the following link. Make sure that it is capacitive touch (WTC):

[AliExpress Display Purchase Link](https://www.aliexpress.us/item/3256803193119661.html)

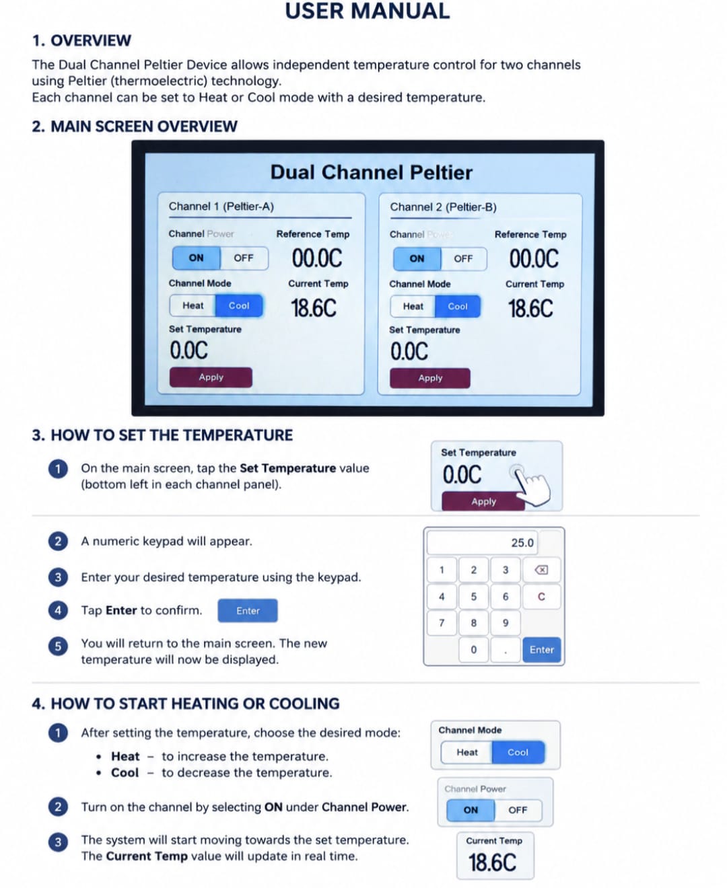
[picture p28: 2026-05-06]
Assembly_and_instructions/User_Manual.jpg

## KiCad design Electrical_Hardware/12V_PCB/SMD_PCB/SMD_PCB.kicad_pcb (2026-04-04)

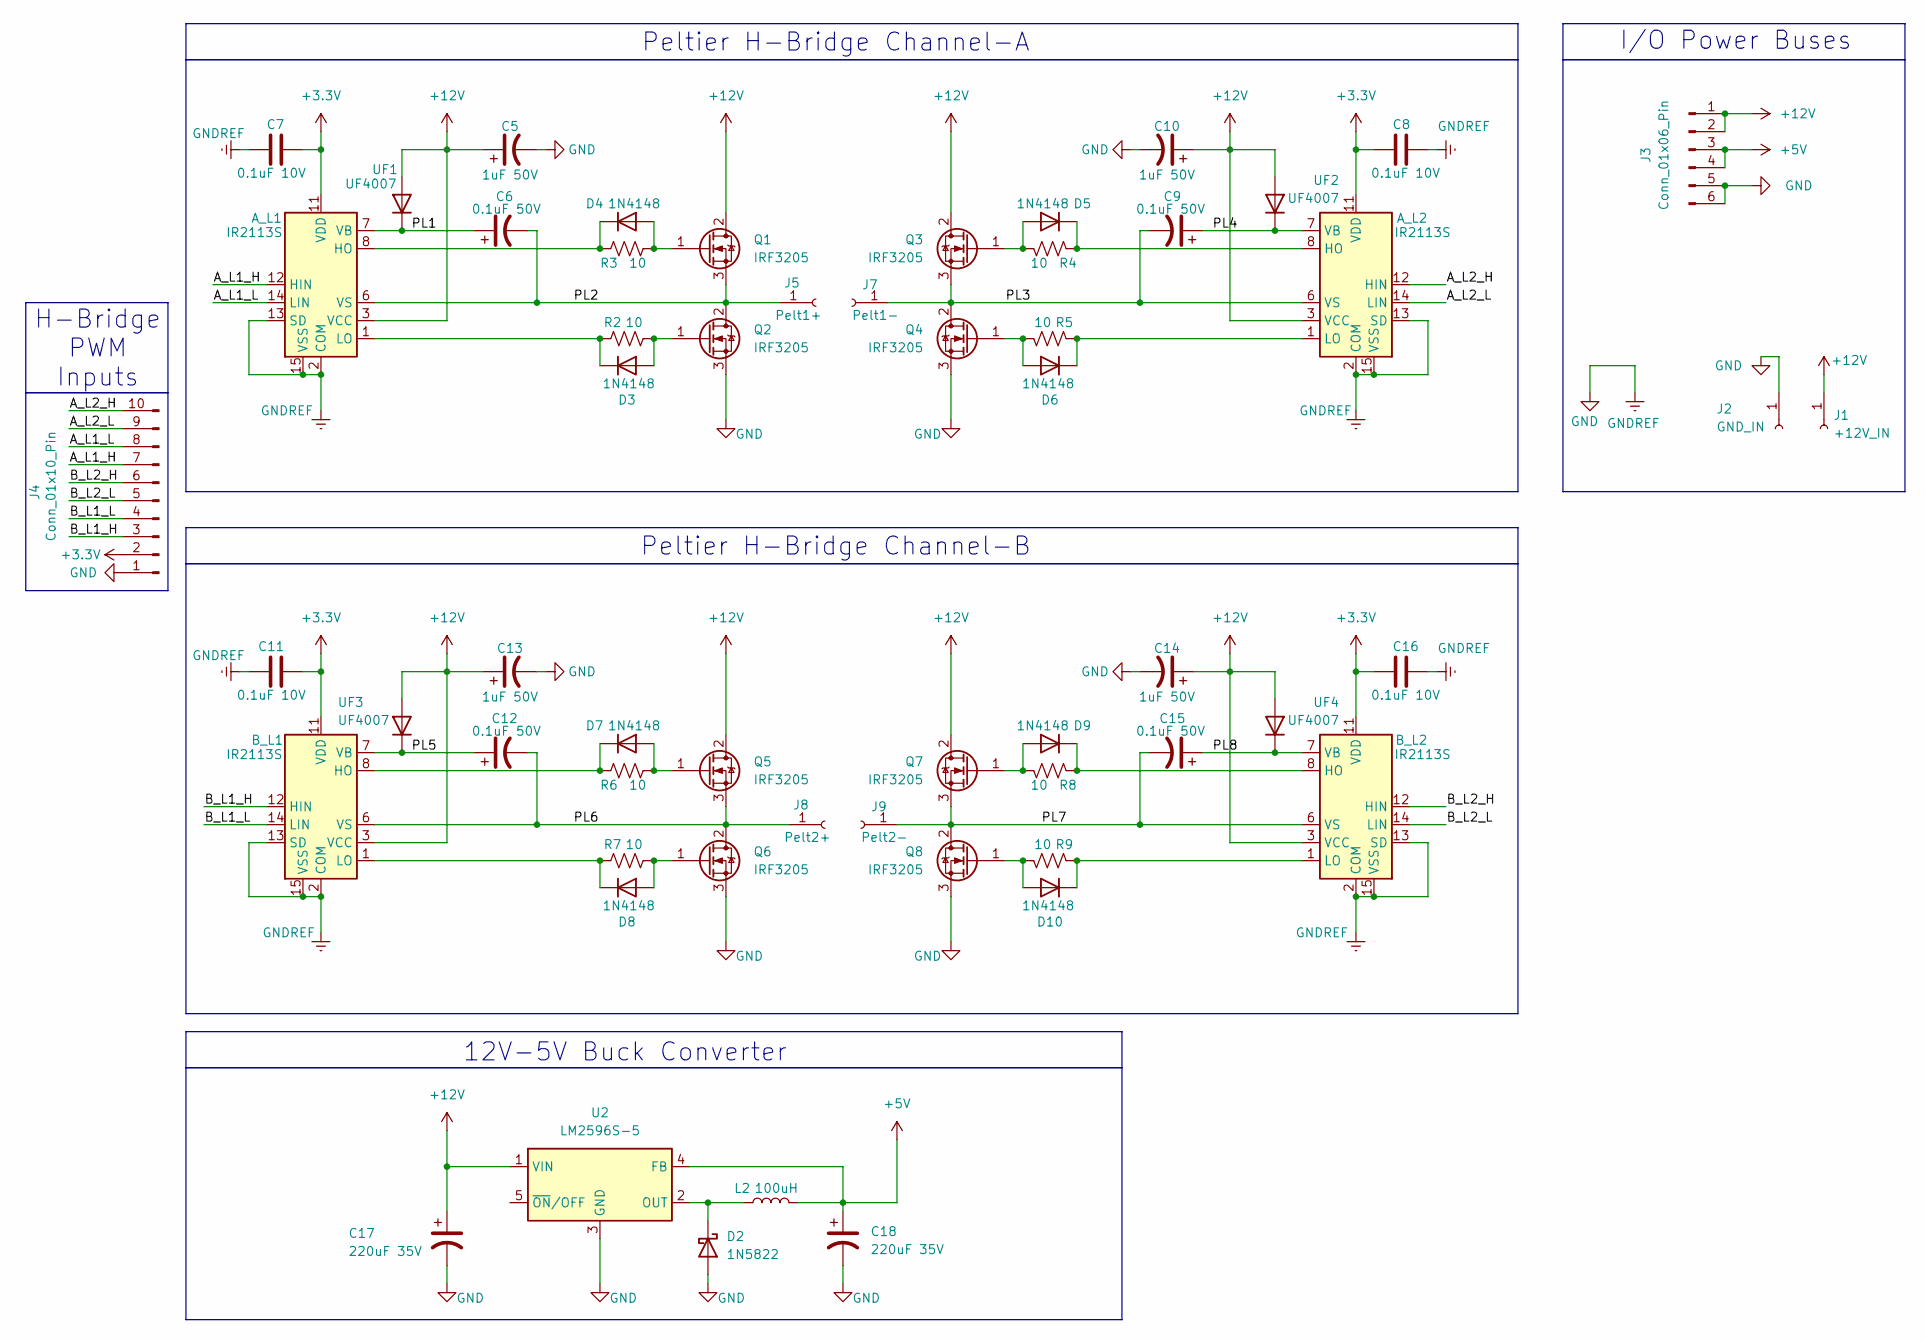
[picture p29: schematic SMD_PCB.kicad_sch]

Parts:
A_L1, A_L2: IR2113S; SOIC-16W_7.5x10.3mm_P1.27mm
B_L1, B_L2: IR2113S; SOIC-16W_7.5x10.3mm_P1.27mm
C5, C10, C13, C14: 1uF 50V; C_1206_3216Metric
C6, C9, C12, C15: 0.1uF 50V; C_1206_3216Metric
C7, C8, C11, C16: 0.1uF 10V; C_1206_3216Metric
C17, C18: 220uF 35V; CP_Elec_8x10
D2: 1N5822; D_SMC
D3, D4, D5, D6, D7, D8, D9, D10: 1N4148; D_SOD-123
J1: +12V_IN; SolderWire-1sqmm_1x01_D1.4mm_OD3.9mm
J2: GND_IN; SolderWire-1sqmm_1x01_D1.4mm_OD3.9mm
J3: Conn_01x06_Pin; PinHeader_1x06_P2.54mm_Vertical
J4: Conn_01x10_Pin; PinHeader_1x10_P2.54mm_Vertical
J5: Pelt1+; SolderWire-1sqmm_1x01_D1.4mm_OD3.9mm
J7: Pelt1-; SolderWire-1sqmm_1x01_D1.4mm_OD3.9mm
J8: Pelt2+; SolderWire-1sqmm_1x01_D1.4mm_OD3.9mm
J9: Pelt2-; SolderWire-1sqmm_1x01_D1.4mm_OD3.9mm
L2: 100uH; L_TDK_SLF12575
Q1, Q2, Q3, Q4, Q5, Q6, Q7, Q8: IRF3205; TO-263-3_TabPin2
R2, R3, R4, R5, R6, R7, R8, R9: 10; R_1206_3216Metric
U2: LM2596S-5; TO-263-5_TabPin3
UF1, UF2, UF3, UF4: UF4007; D_SMA

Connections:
+3.3V: A_L1.11 (VDD), A_L2.11 (VDD), B_L1.11 (VDD), B_L2.11 (VDD), C7.2, C8.2, C11.2, C16.2, J4.2
+5V: C18.1, J3.3, J3.4, L2.2, U2.4 (FB)
+12V: A_L1.3 (VCC), A_L2.3 (VCC), B_L1.3 (VCC), B_L2.3 (VCC), C5.1, C10.1, C13.1, C14.1, C17.1, J1.1, J3.1, J3.2, Q1.2 (D), Q3.2 (D), Q5.2 (D), Q7.2 (D), U2.1 (VIN), UF1.2 (A), UF2.2 (A), UF3.2 (A), UF4.2 (A)
/A_L1_H: A_L1.12 (HIN), J4.7
/A_L1_L: A_L1.14 (LIN), J4.8
/A_L2_H: A_L2.12 (HIN), J4.10
/A_L2_L: A_L2.14 (LIN), J4.9
/B_L1_H: B_L1.12 (HIN), J4.3
/B_L1_L: B_L1.14 (LIN), J4.4
/B_L2_H: B_L2.12 (HIN), J4.6
/B_L2_L: B_L2.14 (LIN), J4.5
/PL1: A_L1.7 (VB), C6.1, UF1.1 (K)
/PL2: A_L1.6 (VS), C6.2, J5.1, Q1.3 (S), Q2.2 (D)
/PL3: A_L2.6 (VS), C9.2, J7.1, Q3.3 (S), Q4.2 (D)
/PL4: A_L2.7 (VB), C9.1, UF2.1 (K)
/PL5: B_L1.7 (VB), C12.1, UF3.1 (K)
/PL6: B_L1.6 (VS), C12.2, J8.1, Q5.3 (S), Q6.2 (D)
/PL7: B_L2.6 (VS), C15.2, J9.1, Q7.3 (S), Q8.2 (D)
/PL8: B_L2.7 (VB), C15.1, UF4.1 (K)
GND: A_L1.2 (COM), A_L1.13 (SD), A_L1.15 (VSS), A_L2.2 (COM), A_L2.13 (SD), A_L2.15 (VSS), B_L1.2 (COM), B_L1.13 (SD), B_L1.15 (VSS), B_L2.2 (COM), B_L2.13 (SD), B_L2.15 (VSS), C5.2, C7.1, C8.1, C10.2, C11.1, C13.2, C14.2, C16.1, C17.2, C18.2, D2.2 (A), J2.1, J3.5, J3.6, J4.1, Q2.3 (S), Q4.3 (S), Q6.3 (S), Q8.3 (S), U2.3 (GND)
unnamed: A_L1.8 (HO), D4.1 (K), R3.1
unnamed: A_L1.1 (LO), D3.1 (K), R2.1
unnamed: A_L2.8 (HO), D5.1 (K), R4.1
unnamed: A_L2.1 (LO), D6.1 (K), R5.1
unnamed: B_L1.8 (HO), D7.1 (K), R6.1
unnamed: B_L1.1 (LO), D8.1 (K), R7.1
unnamed: B_L2.8 (HO), D9.1 (K), R8.1
unnamed: B_L2.1 (LO), D10.1 (K), R9.1
unnamed: D2.1 (K), L2.1, U2.2 (OUT)
unnamed: D3.2 (A), Q2.1 (G), R2.2
unnamed: D4.2 (A), Q1.1 (G), R3.2
unnamed: D5.2 (A), Q3.1 (G), R4.2
unnamed: D6.2 (A), Q4.1 (G), R5.2
unnamed: D7.2 (A), Q5.1 (G), R6.2
unnamed: D8.2 (A), Q6.1 (G), R7.2
unnamed: D9.2 (A), Q7.1 (G), R8.2
unnamed: D10.2 (A), Q8.1 (G), R9.2

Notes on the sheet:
I/O Power Buses
H-Bridge PWM Inputs
Peltier H-Bridge Channel-A
12V-5V Buck Converter
Peltier H-Bridge Channel-B

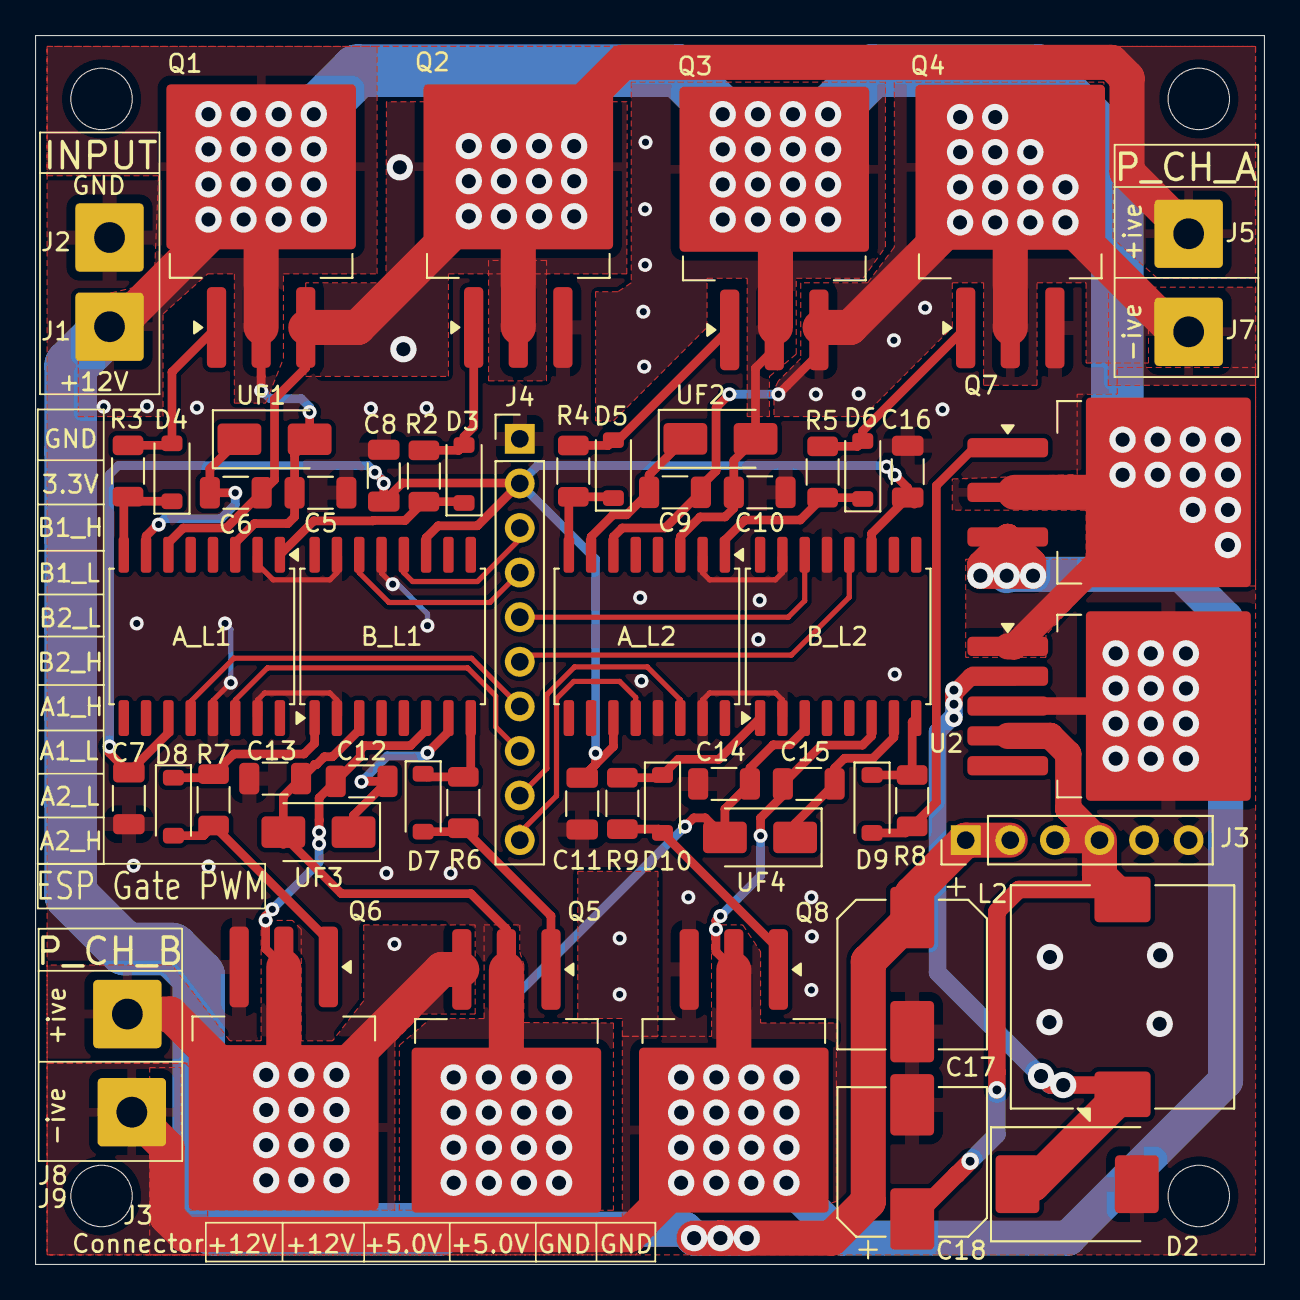
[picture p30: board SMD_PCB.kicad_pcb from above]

Board: 2 copper layers, 70.0 x 70.0 mm, 57 parts (0 on the bottom side), 37 nets.

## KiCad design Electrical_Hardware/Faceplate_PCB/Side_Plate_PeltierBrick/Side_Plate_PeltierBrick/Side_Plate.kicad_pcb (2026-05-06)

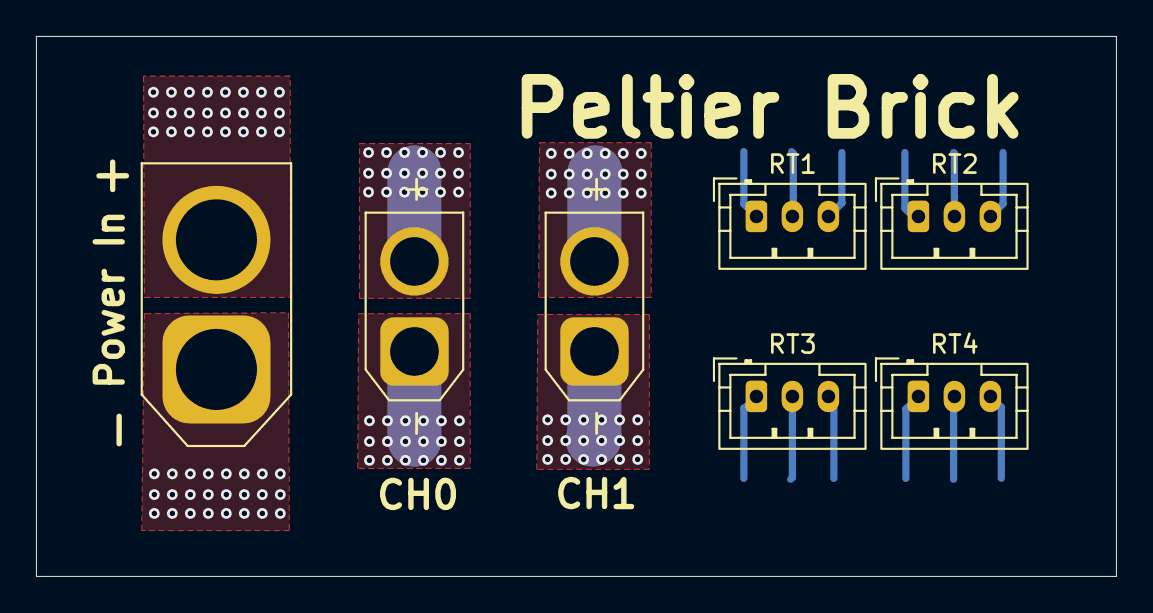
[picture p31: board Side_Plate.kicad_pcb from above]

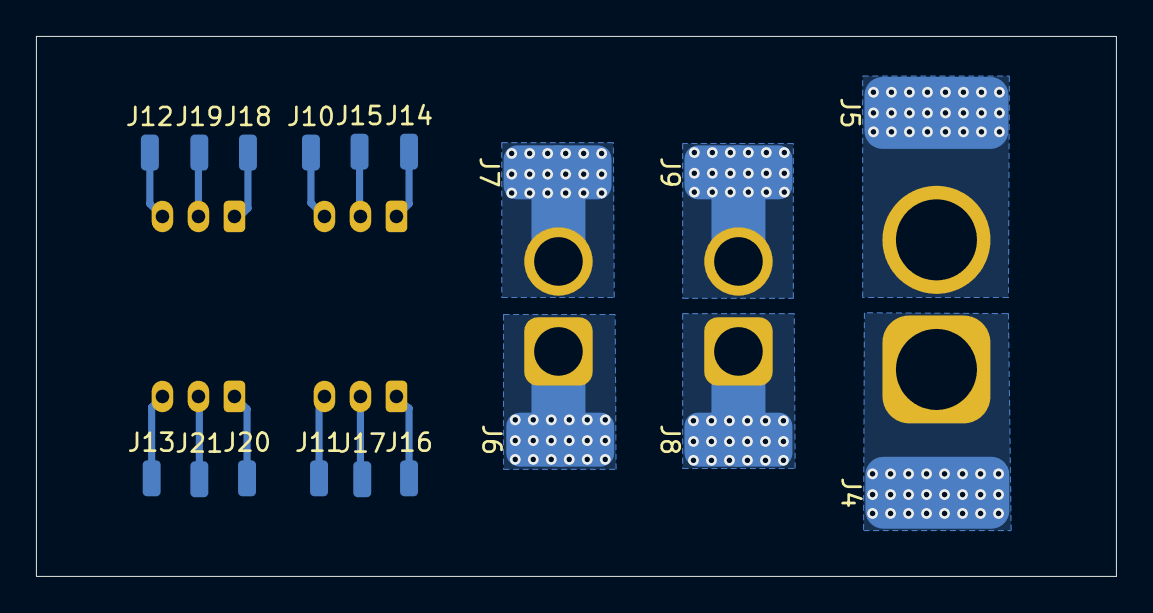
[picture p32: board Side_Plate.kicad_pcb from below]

Board: 2 copper layers, 60.0 x 30.0 mm, 25 parts (18 on the bottom side), 18 nets.

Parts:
J1, J3: Conn_01x02; AMASS_XT30U-M_1x02_P5.0mm_Vertical
J2: Conn_01x02; AMASS_XT60-M_1x02_P7.20mm_Vertical
J4, J5: Conn_01x01; SolderWirePad_1x01_SMD_4x8mm
J6, J7, J8, J9: Conn_01x01; SolderWirePad_1x01_SMD_3x6mm
J10, J11, J12, J13, J14, J15, J16, J17, J18, J19, J20, J21: Conn_01x01; SolderWirePad_1x01_SMD_1x2mm
RT1, RT2, RT3, RT4: Conn_01x03; JST_PH_B3B-PH-K_1x03_P2.00mm_Vertical

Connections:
/CH0_A: J1.1, J8.1
/CH0_B: J1.2, J9.1
/CH1_A: J3.1, J6.1
/CH1_B: J3.2, J7.1
/GND: J2.1, J4.1
/VBUS: J2.2, J5.1
unnamed: J10.1, RT1.3
unnamed: J11.1, RT3.3
unnamed: J12.1, RT2.3
unnamed: J13.1, RT4.3
unnamed: J14.1, RT1.1
unnamed: J15.1, RT1.2
unnamed: J16.1, RT3.1
unnamed: J17.1, RT3.2
unnamed: J18.1, RT2.1
unnamed: J19.1, RT2.2
unnamed: J20.1, RT4.1
unnamed: J21.1, RT4.2

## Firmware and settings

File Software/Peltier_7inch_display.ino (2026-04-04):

#include "driver/mcpwm_prelude.h"

#define LM35_B 17 //A1
#define LM35_A 16 //A2

#define RXD2 38
#define TXD2 39

// Channel/Bridge A
#define A_L1_H 11 
#define A_L1_L 12
#define A_L2_H 18
#define A_L2_L 13

// Channel/Bridge B
#define B_L1_H 5
#define B_L1_L 6
#define B_L2_H 10
#define B_L2_L 9

int currentAddr = 0;
bool channelAON = false;
bool channelBON = false;
bool channelAHeat = false;
bool channelBHeat = false;

float channelARefTemp = 0;
float channelBRefTemp = 0;

int stateA = -1; // -1=Default to Start, 0=OFF, 1=HEAT, 2=COOL
int stateB = -1;

int currentVal = 0;
unsigned long lastWriteTime = 0;
const long interval = 1000; // 1 seconds
bool toggle = false;

mcpwm_timer_handle_t timerA = NULL, timerB = NULL;
mcpwm_oper_handle_t oper1A = NULL, oper2A = NULL, oper1B = NULL, oper2B = NULL;
mcpwm_cmpr_handle_t cmpr1A = NULL, cmpr2A = NULL, cmpr1B = NULL, cmpr2B = NULL;
mcpwm_gen_handle_t g1AH, g1AL, g2AH, g2AL, g1BH, g1BL, g2BH, g2BL;

const uint32_t period = 250; 

void setup() {
    Serial.begin(115200);
    Serial2.begin(115200, SERIAL_8N1, RXD2, TXD2); 
    analogSetAttenuation(ADC_11db);

    // Timer Setup
    mcpwm_timer_config_t timer_conf = {
        .clk_src = MCPWM_TIMER_CLK_SRC_DEFAULT,
        .resolution_hz = 1000000, 
        .count_mode = MCPWM_TIMER_COUNT_MODE_UP,
        .period_ticks = period, 
    };
    
    timer_conf.group_id = 0; mcpwm_new_timer(&timer_conf, &timerA);
    timer_conf.group_id = 1; mcpwm_new_timer(&timer_conf, &timerB);

    mcpwm_comparator_config_t cmpr_conf = {.flags = {.update_cmp_on_tez = true}};
    mcpwm_generator_config_t gen_conf = {};

    // --- H-BRIDGE A ---
    mcpwm_operator_config_t oper_confA = {.group_id = 0};
    mcpwm_new_operator(&oper_confA, &oper1A);
    mcpwm_new_operator(&oper_confA, &oper2A);
    mcpwm_operator_connect_timer(oper1A, timerA);
    mcpwm_operator_connect_timer(oper2A, timerA);
    
    mcpwm_new_comparator(oper1A, &cmpr_conf, &cmpr1A);
    mcpwm_new_comparator(oper2A, &cmpr_conf, &cmpr2A);

    gen_conf.gen_gpio_num = A_L1_H; mcpwm_new_generator(oper1A, &gen_conf, &g1AH);
    gen_conf.gen_gpio_num = A_L1_L; mcpwm_new_generator(oper1A, &gen_conf, &g1AL);
    gen_conf.gen_gpio_num = A_L2_H; mcpwm_new_generator(oper2A, &gen_conf, &g2AH);
    gen_conf.gen_gpio_num = A_L2_L; mcpwm_new_generator(oper2A, &gen_conf, &g2AL);

    // --- H-BRIDGE B  ---
    mcpwm_operator_config_t oper_confB = {.group_id = 1};
    mcpwm_new_operator(&oper_confB, &oper1B);
    mcpwm_new_operator(&oper_confB, &oper2B);
    mcpwm_operator_connect_timer(oper1B, timerB);
    mcpwm_operator_connect_timer(oper2B, timerB);

    mcpwm_new_comparator(oper1B, &cmpr_conf, &cmpr1B);
    mcpwm_new_comparator(oper2B, &cmpr_conf, &cmpr2B);

    gen_conf.gen_gpio_num = B_L1_H; mcpwm_new_generator(oper1B, &gen_conf, &g1BH);
    gen_conf.gen_gpio_num = B_L1_L; mcpwm_new_generator(oper1B, &gen_conf, &g1BL);
    gen_conf.gen_gpio_num = B_L2_H; mcpwm_new_generator(oper2B, &gen_conf, &g2BH);
    gen_conf.gen_gpio_num = B_L2_L; mcpwm_new_generator(oper2B, &gen_conf, &g2BL);

    // Generate PWM
    mcpwm_generator_set_action_on_timer_event(g1AH, MCPWM_GEN_TIMER_EVENT_ACTION(MCPWM_TIMER_DIRECTION_UP, MCPWM_TIMER_EVENT_EMPTY, MCPWM_GEN_ACTION_HIGH));
    mcpwm_generator_set_action_on_compare_event(g1AH, MCPWM_GEN_COMPARE_EVENT_ACTION(MCPWM_TIMER_DIRECTION_UP, cmpr1A, MCPWM_GEN_ACTION_LOW));
    mcpwm_generator_set_action_on_timer_event(g2AH, MCPWM_GEN_TIMER_EVENT_ACTION(MCPWM_TIMER_DIRECTION_UP, MCPWM_TIMER_EVENT_EMPTY, MCPWM_GEN_ACTION_HIGH));
    mcpwm_generator_set_action_on_compare_event(g2AH, MCPWM_GEN_COMPARE_EVENT_ACTION(MCPWM_TIMER_DIRECTION_UP, cmpr2A, MCPWM_GEN_ACTION_LOW));

    mcpwm_generator_set_action_on_timer_event(g1BH, MCPWM_GEN_TIMER_EVENT_ACTION(MCPWM_TIMER_DIRECTION_UP, MCPWM_TIMER_EVENT_EMPTY, MCPWM_GEN_ACTION_HIGH));
    mcpwm_generator_set_action_on_compare_event(g1BH, MCPWM_GEN_COMPARE_EVENT_ACTION(MCPWM_TIMER_DIRECTION_UP, cmpr1B, MCPWM_GEN_ACTION_LOW));
    mcpwm_generator_set_action_on_timer_event(g2BH, MCPWM_GEN_TIMER_EVENT_ACTION(MCPWM_TIMER_DIRECTION_UP, MCPWM_TIMER_EVENT_EMPTY, MCPWM_GEN_ACTION_HIGH));
    mcpwm_generator_set_action_on_compare_event(g2BH, MCPWM_GEN_COMPARE_EVENT_ACTION(MCPWM_TIMER_DIRECTION_UP, cmpr2B, MCPWM_GEN_ACTION_LOW));

    mcpwm_timer_enable(timerA);
    mcpwm_timer_start_stop(timerA, MCPWM_TIMER_START_NO_STOP);
    mcpwm_timer_enable(timerB);
    mcpwm_timer_start_stop(timerB, MCPWM_TIMER_START_NO_STOP);

    peltierA_OFF();
    peltierB_OFF();

    //peltierB_Cool(90); // TEST RUN JD
}
void peltierA_OFF() {
    mcpwm_generator_set_force_level(g1AH, 0, true); mcpwm_generator_set_force_level(g1AL, 0, true);
    mcpwm_generator_set_force_level(g2AH, 0, true); mcpwm_generator_set_force_level(g2AL, 0, true);
}

void peltierA_Cool(int duty) {
    mcpwm_comparator_set_compare_value(cmpr1A, (duty * period) / 100);
    mcpwm_generator_set_force_level(g1AH, -1, true); 
    mcpwm_generator_set_force_level(g2AL, 1, true);  
}

void peltierA_Heat(int duty) {
    mcpwm_comparator_set_compare_value(cmpr2A, (duty * period) / 100);
    mcpwm_generator_set_force_level(g2AH, -1, true); 
    mcpwm_generator_set_force_level(g1AL, 1, true);  
}

void peltierB_OFF() {
    mcpwm_generator_set_force_level(g1BH, 0, true); mcpwm_generator_set_force_level(g1BL, 0, true);
    mcpwm_generator_set_force_level(g2BH, 0, true); mcpwm_generator_set_force_level(g2BL, 0, true);
}

void peltierB_Cool(int duty) {
    mcpwm_comparator_set_compare_value(cmpr1B, (duty * period) / 100);
    mcpwm_generator_set_force_level(g1BH, -1, true); 
    mcpwm_generator_set_force_level(g2BL, 1, true);  
}

void peltierB_Heat(int duty) {
    mcpwm_comparator_set_compare_value(cmpr2B, (duty * period) / 100);
    mcpwm_generator_set_force_level(g2BH, -1, true); 
    mcpwm_generator_set_force_level(g1BL, 1, true);  
}

bool readDWIN(int *addr, int *val) {
  if (Serial2.available() >= 3) {
    if (Serial2.read() == 0x5A) {
      if (Serial2.peek() == 0xA5) {
        Serial2.read();
        
        byte len = Serial2.read();
        byte frame[len];

        // Fill frame array
        for (int i = 0; i < len; i++) {
          uint32_t startWait = millis();
          while (Serial2.available() == 0) {
            if (millis() - startWait > 50) return false;
          }
          frame[i] = Serial2.read();
        }

        if (frame[0] == 0x83) {
          *addr = (frame[1] << 8) | frame[2];
          *val  = (frame[4] << 8) | frame[5];  
          return true;
        }
      }
    }
  }
  return false;
}

void writeDWINLong(int addr, long value) {
  byte frame[10]; 
  
  frame[0] = 0x5A;            
  frame[1] = 0xA5;            
  frame[2] = 0x07;           
  frame[3] = 0x82;            
  frame[4] = highByte(addr);  
  frame[5] = lowByte(addr);   
  
  frame[6] = (value >> 24) & 0xFF; 
  frame[7] = (value >> 16) & 0xFF; 
  frame[8] = (value >> 8)  & 0xFF;
  frame[9] = (value)       & 0xFF; 
  
  Serial2.write(frame, 10); 
  
  //Serial.printf("Sent Long to 0x%04X: %ld\n", addr, value);
}

float getTemp(int pin) {
  float sum = 0;
  for(int i = 0; i < 20; i++) {
    sum += (analogRead(pin) * 3.3 / 4095.0) * 100.0;
  }
  return sum / 20.0;
}

void readInputState(){
        if (readDWIN(&currentAddr, &currentVal)) {
        Serial.printf("Addr: 0x%04X | Val: %d\n", currentAddr, currentVal);
        
        if (currentAddr == 0x6500 && currentVal == 1) {
            Serial.println("Turn ON Channel A");
            channelAON = true;
        }
        else if (currentAddr == 0x6500 && currentVal == 0) {
            Serial.println("Turn OFF Channel A");
            channelAON = false;
        }

        if (currentAddr == 0x6700 && currentVal == 1) {
            Serial.println("Turn ON Channel B");
            channelBON = true;
        }
        else if (currentAddr == 0x6700 && currentVal == 0) {
            Serial.println("Turn OFF Channel B");
            channelBON = false;
        }

        if (currentAddr == 0x6600 && currentVal == 1) {
            Serial.println("Heat Channel A");
            channelAHeat = true;
        }
        else if (currentAddr == 0x6600 && currentVal == 0) {
            Serial.println("Cool Channel A");
            channelAHeat = false;
        }

        if (currentAddr == 0x6800 && currentVal == 1) {
            Serial.println("Heat Channel B");
            channelBHeat = true;
        }
        else if (currentAddr == 0x6800 && currentVal == 0) {
            Serial.println("Cool Channel B");
            channelBHeat = false;
        }
        if (currentAddr == 0x2000) {
            Serial.print("Set Temperature of Channel A to ");
            Serial.print(currentVal);
            Serial.println();
            channelARefTemp = currentVal/10.0;
            writeDWINLong(0x5500, currentVal);
            delay(50);
        }
        if (currentAddr == 0x2100) {
            Serial.print("Set Temperature of Channel B to ");
            Serial.print(currentVal);
            Serial.println();
            channelBRefTemp = currentVal/10.0;
            writeDWINLong(0x5700, currentVal);
            delay(50);
        }
    }
}

void updateTemp(){
    float channelATemp = getTemp(LM35_A);
    float channelBTemp = getTemp(LM35_B);

    if (millis() - lastWriteTime >= interval) {
        lastWriteTime = millis();
        writeDWINLong(0x5600, (long)(channelATemp * 10));
        delay(50);
        writeDWINLong(0x5800, (long)(channelBTemp * 10));
    }
}

void loop() {
//NOTE FOR JAWAD: Always have both peltier OFF before turning ON/OFF a peltier or switching from heat/cool
    // peltierA_OFF(); peltierB_OFF();
    //peltierA_Cool(90);
    //peltierB_Cool(90);
    //delay(60000);

    updateTemp();
    readInputState();

    if (channelAON){
        Serial.printf("Ref: %.2f, Actual: %.2f\n", channelARefTemp, getTemp(LM35_A));
        if (channelAHeat){
            if (channelARefTemp > getTemp(LM35_A)+0.5){
                peltierA_Heat(90);
            }
            else{
                peltierA_OFF();
            }
            
        }
        else{
            if (channelARefTemp < getTemp(LM35_A)-0.5){
                peltierA_Cool(90);
            }
            else{
                peltierA_OFF();
            }
        }
    }
    else{
        peltierA_OFF();
    }


    if (channelBON){
        Serial.printf("Channel B Ref: %.2f, Actual: %.2f\n", channelBRefTemp, getTemp(LM35_B));
        if (channelBHeat){
            if (channelBRefTemp > getTemp(LM35_B)+0.5){
                peltierB_Heat(90);
            }
            else{
                peltierB_OFF();
            }
            
        }
        else{
            if (channelBRefTemp < getTemp(LM35_B)-0.5){
                peltierB_Cool(90);
            }
            else{
                peltierB_OFF();
            }
        }
    }
    else{
        peltierB_OFF();
    }
}

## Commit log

2026-03-07 Uploaded some basic documentation files and PCB design.
    [BOM peltier smd .xlsx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]
2026-04-04 Add GUI module, update PCB design, and improve README documentation
    [BOM peltier smd .xlsx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]
2026-05-06 renew the PCB_floder, uploaded the Assembly Instruction and users manul
    [Amass_MR30PB-FB.step, Amass_MR30PB-M.step, Amass_XT30UPB-F.step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]
